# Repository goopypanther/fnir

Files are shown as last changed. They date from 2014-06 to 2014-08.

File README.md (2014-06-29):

fNIR: Functional Near-Infrared Brain Imaging
============================================

Similar to a pulse oximiter, an fNIR imager sends pulses of near infrared light into the body and records the intensity of the reflection to determine blood oxygen levels. At these frequencies bone is nearly transparent so sensors placed on the head can measure oxygen levels in the outer layers of the brain. These tend to correspond over time with the levels of activity of those regions.

This fNIR system has 8 groupings of transmitter LEDs and 10 receivers clustered around them which provides 16 measurement channels. Each LED cluster can illuminate the brain with either of two frequencies, one which reflects strongly off oxygenated hemoglobin and the other non-oxygenated. Calculating the ratio between the two yields the target's oxygen concentration.

The sensors are meant to be installed in a headband which can target the frontal lobe (short term memory, complex thought), primary motor cortex (voluntary movement), or even the broca's area or visual cortex.

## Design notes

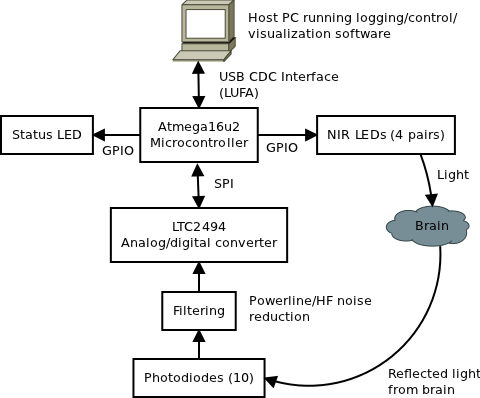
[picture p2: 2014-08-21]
system_design_document/system_design_document.png

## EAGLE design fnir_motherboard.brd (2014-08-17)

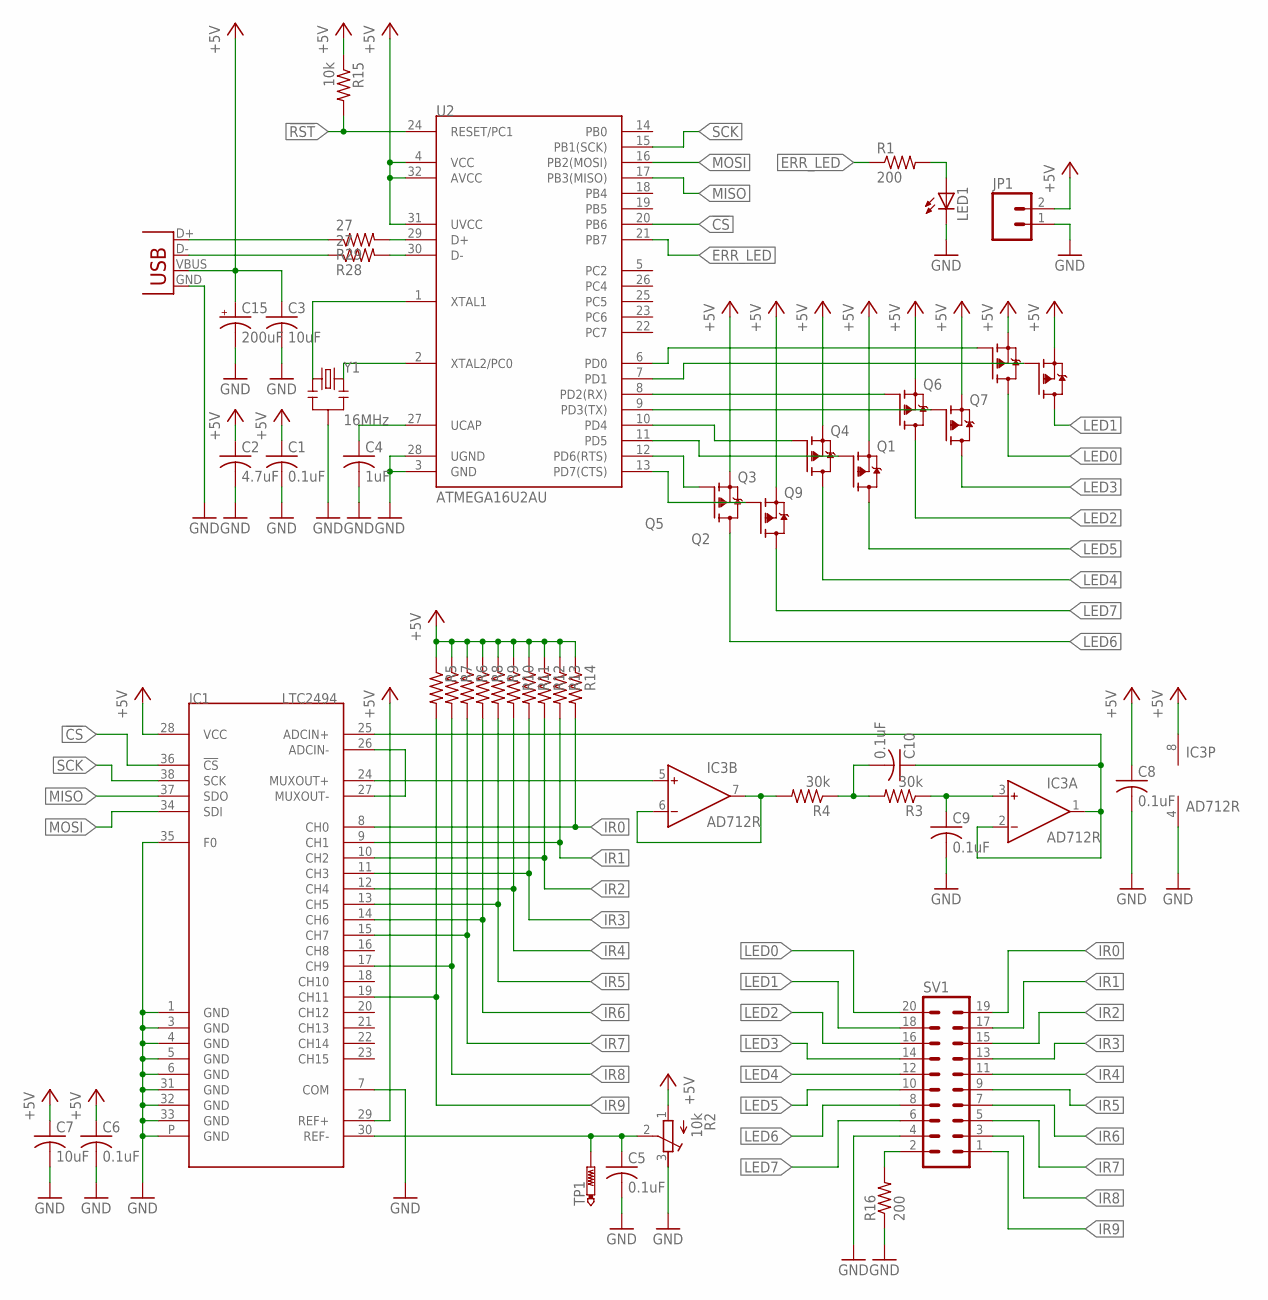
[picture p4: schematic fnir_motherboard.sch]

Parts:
C1, C5, C6, C8, C9, C10: 0.1uF; C1206
C2: 4.7uF; C1206
C3, C7: 10uF; C1206
C4: 1uF; C1206
C15: 200uF; PANASONIC_D
IC1: LTC2494; QFN38-7X12
IC3: AD712R; SO8
JP1: M02PTH; 1X02
LED1: LEDCHIPLED_1206; CHIPLED_1206
Q1, Q2, Q3, Q4, Q5, Q6, Q7, Q9: TRANSISTOR_FET_TSM2301CX; SOT-23
R1, R16: 200; R1206
R2: 10k; RTRIM3304W
R3, R4: 30k; R1206
R5, R6, R7, R8, R9, R10, R11, R12, R13, R14: R-US_R1206; R1206
R15: 10k; R1206
R28, R29: 27; R1206
SV1: MA10-2
TP1: PTR1B1,27; B1,27
U2: ATMEGA16U2AU; TQFP32-08
X2: USB-SMD-NS; USB-MINIB-NOSTOP
Y1: 16MHz; RESONATOR-SMD

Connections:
!CS: IC1.36 (!CS), U2.20 (PB6)
!RST: R15.2, U2.24 (RESET/PC1)
+5V: C1.1, C2.1, C3.1, C6.1, C7.1, C8.1, C15.+, IC1.28 (VCC), IC1.29 (REF+), IC3.8 (V+), JP1.2, Q1.2 (S), Q2.2 (S), Q3.2 (S), Q4.2 (S), Q5.2 (S), Q6.2 (S), Q7.2 (S), Q9.2 (S), R2.1 (A), R5.1, R6.1, R7.1, R8.1, R9.1, R10.1, R11.1, R12.1, R13.1, R14.1, R15.1, U2.4 (VCC), U2.31 (UVCC), U2.32 (AVCC), X2.VBUS
D+: R29.1, X2.D+
D-: R28.1, X2.D-
ERR_LED: R1.1, U2.21 (PB7)
GND: C1.2, C2.2, C3.2, C4.2, C5.2, C6.2, C7.2, C8.2, C9.2, C15.-, IC1.1 (GND), IC1.3 (GND), IC1.4 (GND), IC1.5 (GND), IC1.6 (GND), IC1.7 (COM), IC1.31 (GND), IC1.32 (GND), IC1.33 (GND), IC1.35 (F0), IC1.P (GND), IC3.4 (V-), JP1.1, LED1.C, R2.3 (E), R16.1, SV1.4, U2.3 (GND), U2.28 (UGND), X2.GND, Y1.2
IR0: IC1.8 (CH0), R14.2, SV1.19
IR1: IC1.9 (CH1), R13.2, SV1.17
IR2: IC1.10 (CH2), R12.2, SV1.15
IR3: IC1.11 (CH3), R11.2, SV1.13
IR4: IC1.12 (CH4), R10.2, SV1.11
IR5: IC1.13 (CH5), R9.2, SV1.9
IR6: IC1.14 (CH6), R8.2, SV1.7
IR7: IC1.15 (CH7), R6.2, SV1.5
IR8: IC1.17 (CH9), R7.2, SV1.3
IR9: IC1.19 (CH11), R5.2, SV1.1
LED0: Q6.3 (D), SV1.20
LED1: Q7.3 (D), SV1.18
LED2: Q4.3 (D), SV1.16
LED3: Q1.3 (D), SV1.14
LED4: Q3.3 (D), SV1.12
LED5: Q9.3 (D), SV1.10
LED6: Q5.3 (D), SV1.8
LED7: Q2.3 (D), SV1.6
MISO: IC1.37 (SDO), U2.17 (PB3(MISO))
MOSI: IC1.34 (SDI), U2.16 (PB2(MOSI))
unnamed: Q2.1 (G), U2.13 (PD7(CTS))
unnamed: Q1.1 (G), U2.9 (PD3(TX))
unnamed: Q9.1 (G), U2.11 (PD5)
unnamed: Q4.1 (G), U2.8 (PD2(RX))
unnamed: Q5.1 (G), U2.12 (PD6(RTS))
unnamed: Q7.1 (G), U2.7 (PD1)
unnamed: Q6.1 (G), U2.6 (PD0)
unnamed: Q3.1 (G), U2.10 (PD4)
unnamed: IC1.26 (ADCIN-), IC1.27 (MUXOUT-)
unnamed: IC1.24 (MUXOUT+), IC3.5 (IN+)
unnamed: C10.1, IC1.25 (ADCIN+), IC3.1 (OUT), IC3.2 (IN-)
unnamed: C5.1, IC1.30 (REF-), R2.2 (S), TP1.TP
unnamed: C9.1, IC3.3 (IN+), R3.1
unnamed: R28.2, U2.30 (D-)
unnamed: R29.2, U2.29 (D+)
unnamed: C10.2, R3.2, R4.1
unnamed: C4.1, U2.27 (UCAP)
unnamed: IC3.6 (IN-), IC3.7 (OUT), R4.2
unnamed: U2.2 (XTAL2/PC0), Y1.3
unnamed: U2.1 (XTAL1), Y1.1
unnamed: LED1.A, R1.2
unnamed: R16.2, SV1.2
SCK: IC1.38 (SCK), U2.15 (PB1(SCK))

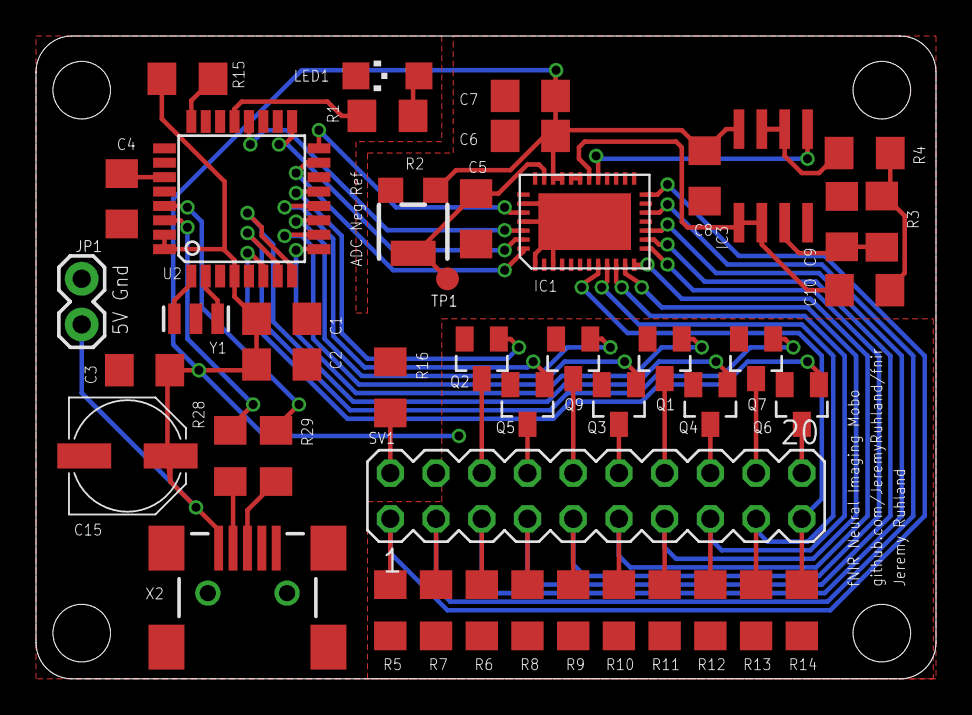
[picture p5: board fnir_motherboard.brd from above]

Board: 2 copper layers, 50.0 x 35.7 mm, 46 parts (0 on the bottom side), 50 nets.

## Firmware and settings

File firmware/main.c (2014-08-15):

/** @file main.c
* @brief fNIR Brain Imager
* @author Jeremy Ruhland
* @date 8/2014
*/

#include "includes.h"

// Private typedefs
/** USB system state enum */
typedef enum {USB_CONNECTED, /**< Usb system connected */
              USB_IDLE /**< Usb system disconnected */
} USB_sys_state_t;

/** fNIR scanning mode enum */
typedef enum {FNIR_NULL, /**< System is taking null offset measurement */
              FNIR_730NM, /**< System is taking 730nm measurement */
              FNIR_850NM, /**< System is taking 850nm measurement */
              FNIR_IDLE, /**< System is not currently taking any measurement */
              FNIR_STOP /**< System is paused and will not take measurements */
} fnir_mode_state_t;

// Private define macros
#define LED_ON() PORTB |= (1<<PB7)
#define LED_OFF() PORTB &= ~(1<<PB7)
#define LED_TOGGLE() PORTB ^= (1<<PB7)
#define CHIP_SELECT() PORTB |= (1<<PB6)
#define CHIP_DESELECT() PORTB &= ~(1<<PB6)

// Function prototypes
void mainIoInit(void);
void mainParseCommand(uint8_t receivedByte);
void mainFnirScan(void);
void mainNirLedControl(fnir_mode_state_t fnirMode, uint8_t channel);
adcReturn_t mainTakeMeasurement(uint8_t channel);
void mainReportResult(uint8_t channel, adcReturn_t *adcReturnValue);
void EVENT_USB_Device_Connect(void);
void EVENT_USB_Device_Disconnect(void);
void EVENT_USB_Device_ConfigurationChanged(void);
void EVENT_USB_Device_ControlRequest(void);

// Global variables
USB_sys_state_t USBSystemState;
fnir_mode_state_t fnirModeState;
static FILE USBSerialStream;

// Class define for USB CDC interface, taken from usb-serial example
USB_ClassInfo_CDC_Device_t VirtualSerial_CDC_Interface = {
    .Config = {
        .ControlInterfaceNumber = INTERFACE_ID_CDC_CCI,
        .DataINEndpoint = {
            .Address = CDC_TX_EPADDR,
            .Size = CDC_TXRX_EPSIZE,
            .Banks = 1,
        },
        .DataOUTEndpoint = {
            .Address = CDC_RX_EPADDR,
            .Size = CDC_TXRX_EPSIZE,
            .Banks = 1,
        },
        .NotificationEndpoint = {
            .Address = CDC_NOTIFICATION_EPADDR,
            .Size = CDC_NOTIFICATION_EPSIZE,
            .Banks = 1,
        },
    },
};

/** Main function
*
* Program begins here upon bootup
*
* @return This function should never exit.
*/
int main(void) {
    uint8_t receivedByte;

    USBSystemState = USB_IDLE;
    fnirModeState = FNIR_STOP;

    mainIoInit();
    spiInit();

    sei();

    for (;;) {
        switch (USBSystemState) {
        // When disconnected, attempt to reconnect
        case (USB_IDLE) :
            LED_TOGGLE();
            USB_Init();
            CDC_Device_CreateStream(&VirtualSerial_CDC_Interface, &USBSerialStream);
            break;

        // When connected, parse any received char and take measurements
        case (USB_CONNECTED) :
            LED_ON();
            receivedByte = fgetc(&USBSerialStream);
            mainParseCommand(receivedByte);
            mainFnirScan();

            // Calls to LUFA
            CDC_Device_USBTask(&VirtualSerial_CDC_Interface);
            USB_USBTask();
            break;

        default :
            break;
        }
    }
}

/** Initializes LED output for debug and NIR leds & SPI ports.
*
*/
void mainIoInit(void) {
    // Debug LED
    LED_OFF();
    DDRB |= (1<<PB7);

    // SPI
    DDRB |= ((1<<PB1)|(1<<PB2));

    // LED FETs
    mainNirLedControl(FNIR_NULL, 0);
    DDRD |= 0xFF; // Turn all port d IO to outputs
}

/** Parses commands received over usb-serial from host computer
*
* Checks the received byte from the usb serial stream device
* \ref USBSerialStream and passes it through a switch statement.
* Able to start and stop continuous measurements with chars \c s & \c p.
*
* @param receivedByte ASCII char received via usb-serial to be parsed
*/
void mainParseCommand(uint8_t receivedByte) {
    // Handle messages from host
    switch (receivedByte) {
    case (EOF) :
        break;

    case ('s') :
        fprintf(&USBSerialStream, "Starting\r\n");
        fnirModeState = FNIR_IDLE;
        break;

    case ('p') :
        fprintf(&USBSerialStream, "Stopping\r\n");
        fnirModeState = FNIR_STOP;

    default :
        break;
    }
}

/** Handles measurement of subject
*
* Cycles through all 16 channels, taking measurements with both types of LEDs
* as well as a non-LED measurement to calculate an offset value.
*
*/
void mainFnirScan(void) {
    static uint8_t measurementChannelSelected = 0;
    static adcReturn_t voltageLevel[3];

    switch (fnirModeState) {
    case (FNIR_NULL) :
        fnirModeState = FNIR_730NM;
        break;

    case (FNIR_730NM) :
        mainNirLedControl(fnirModeState, measurementChannelSelected);
        voltageLevel[0] = mainTakeMeasurement(measurementChannelSelected);
        fnirModeState = FNIR_850NM;
        break;

    case (FNIR_850NM) :
        mainNirLedControl(fnirModeState, measurementChannelSelected);
        voltageLevel[1] = mainTakeMeasurement(measurementChannelSelected);
        fnirModeState = FNIR_IDLE;
        break;

    case (FNIR_IDLE) :
        mainNirLedControl(fnirModeState, measurementChannelSelected);
        voltageLevel[2] = mainTakeMeasurement(measurementChannelSelected);
        fnirModeState = FNIR_NULL;

        // Send measurement via USB.
        mainReportResult(measurementChannelSelected, voltageLevel);

        // Move on to next measurement channel, or start back at 0
        if (measurementChannelSelected < 16) {
            measurementChannelSelected++;
        } else {
            measurementChannelSelected = 0;
        }
        break;

    case (FNIR_STOP) :
        break;

    default:
        break;
    }
}

/** Controls selection of near infrared leds.
*
* Channel may be 0-3, all leds will turn off when
* fnirMode == FNIR_IDLE | FNIR_NULL | FNIR_STOP.
*
* @param fnirMode LED type to activate
* @param channel led to activate
*/
void mainNirLedControl(fnir_mode_state_t fnirMode, uint8_t channel) {
    uint8_t ledChannel;

    ledChannel = channel/4; // Determine LED pair from desired channel

    // Activate proper led for desired mode and channel
    if (fnirMode == FNIR_730NM) {
        switch (ledChannel) {
        case 0 :
            PORTD = (1<<PD0);
            break;

        case 1 :
            PORTD = (1<<PD2);
            break;

        case 2 :
            PORTD = (1<<PD4);
            break;

        case 3 :
            PORTD = (1<<PD6);
            break;

        default :
            break;
        }
    } else if (fnirMode == FNIR_850NM) {
        switch (ledChannel) {
        case 0 :
            PORTD = (1<<PD1);
            break;

        case 1 :
            PORTD = (1<<PD3);
            break;

        case 2 :
            PORTD = (1<<PD5);
            break;

        case 3 :
            PORTD = (1<<PD7);
            break;

        default :
            break;
        }
    // If fnirMode was FNIR_IDLE|FNIR_NULL|FNIR_STOP
    } else {
        PORTD = 0x00; // Turn off all IO on port D
    }
}

/** Retrieves measurement from ADC
*
* Commands ADC to take measurement from selected channel with selected
* settings. Blocks until result is returned.
*
* @param channel channel of measurement to retrieve.
* @return measurement data
*/
adcReturn_t mainTakeMeasurement(uint8_t channel) {
    adcReturn_t adcReturnValue;
    adcChannelType_t adcChannel;

    // Determine multiplexer setup for desired channel
    switch (channel) {
    case 0 :
        adcChannel = UNIPOLAR_CH_0;
        break;

    case 1 :
        adcChannel = UNIPOLAR_CH_1;
        break;

    case 2 :
    case 4 :
        adcChannel = UNIPOLAR_CH_2;
        break;

    case 3 :
    case 5 :
        adcChannel = UNIPOLAR_CH_3;
        break;

    case 6 :
    case 8 :
        adcChannel = UNIPOLAR_CH_4;
        break;

    case 7 :
    case 9 :
        adcChannel = UNIPOLAR_CH_5;
        break;

    case 10 :
    case 12 :
        adcChannel = UNIPOLAR_CH_6;
        break;

    case 11 :
    case 13 :
        adcChannel = UNIPOLAR_CH_7;
        break;

    case 14 :
        adcChannel = UNIPOLAR_CH_9;
        break;

    case 15 :
        adcChannel = UNIPOLAR_CH_11;
        break;

    default :
        break;
    }

    CHIP_SELECT();

    // Command ADC to begin conversion
    (void) adcSelect(ENABLE,         // Enable adc
                     adcChannel,     // Select channel
                     REJECT_60HZ,    // Reject 60hz powerline noise
                     AUTO_CALIBRATE, // Slower but more accurate speed
                     GAIN_1X);       // Unity gain (no amplification)

    while (PORTB & (1<<PB3)) {} // Wait for conversion complete

    // Get return value while commanding ADC to shutdown
    adcReturnValue = adcSelect(DISABLE,        // Disable adc
                               NULL_CH,        // Null channel
                               NULL_REJECTION, // Null frequency rejection
                               NULL_SPEED,     // Null conversion speed
                               NULL_GAIN);     // Null signal gain

    CHIP_DESELECT();

    return (adcReturnValue);
}

/** Reports CVS dataset of measurements over USB
*
* TODO: calculate estimated oxy content from received values
*
* @param channel channel measured
* @param adcReturnValue array of measurements taken from specific channel
*/
void mainReportResult(uint8_t channel, adcReturn_t *adcReturnValue) {
    uint16_t estimatedOxyContent;

    fprintf(&USBSerialStream, "%d,%d,%d,%d,%d\r\n", // CSV string
            ((uint16_t) channel),                   // Reported channel
            adcReturnValue[0].returnValue,          // 730nm result
            adcReturnValue[1].returnValue,          // 850nm result
            adcReturnValue[2].returnValue,          // Dark result
            estimatedOxyContent);                   // Calculated oxy value
}

/** Event handler for the library USB Connection event. 
*
* Stops connection attempts from being made after the host device enumerates
* the system and prints "Device connected" onto the serial terminal.
* 
* @return This function does not return a value.
*/
void EVENT_USB_Device_Connect(void) {
    fprintf(&USBSerialStream, "Device Connected\r\n");
    USBSystemState = USB_CONNECTED;
}

/** Event handler for the library USB Disconnection event.
*
* Starts looping device connection attempts when if device becomes
* disconnected.
*
* @return This function does not return a value.
*/
void EVENT_USB_Device_Disconnect(void) {
    USBSystemState = USB_IDLE;
}

/** Event handler for the library USB Configuration Changed event.
*
*
* @return This function does not return a value.
*/
void EVENT_USB_Device_ConfigurationChanged(void) {
    CDC_Device_ConfigureEndpoints(&VirtualSerial_CDC_Interface);
}

/** Event handler for the library USB Control Request reception event.
*
* @return This function does not return a value.
*/
void EVENT_USB_Device_ControlRequest(void) {
    CDC_Device_ProcessControlRequest(&VirtualSerial_CDC_Interface);
}

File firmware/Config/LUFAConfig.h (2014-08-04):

/*
             LUFA Library
     Copyright (C) Dean Camera, 2014.

  dean [at] fourwalledcubicle [dot] com
           www.lufa-lib.org
*/

/*
  Copyright 2014  Dean Camera (dean [at] fourwalledcubicle [dot] com)

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
  The author disclaims all warranties with regard to this
  software, including all implied warranties of merchantability
  and fitness.  In no event shall the author be liable for any
  special, indirect or consequential damages or any damages
  whatsoever resulting from loss of use, data or profits, whether
  in an action of contract, negligence or other tortious action,
  arising out of or in connection with the use or performance of
  this software.
*/

/** \file
 *  \brief LUFA Library Configuration Header File
 *
 *  This header file is used to configure LUFA's compile time options,
 *  as an alternative to the compile time constants supplied through
 *  a makefile.
 *
 *  For information on what each token does, refer to the LUFA
 *  manual section "Summary of Compile Tokens".
 */

#ifndef _LUFA_CONFIG_H_
#define _LUFA_CONFIG_H_

	#if (ARCH == ARCH_AVR8)
		/* Non-USB Related Configuration Tokens: */
//		#define DISABLE_TERMINAL_CODES

		/* USB Class Driver Related Tokens: */
//		#define HID_HOST_BOOT_PROTOCOL_ONLY
//		#define HID_STATETABLE_STACK_DEPTH       {Insert Value Here}
//		#define HID_USAGE_STACK_DEPTH            {Insert Value Here}
//		#define HID_MAX_COLLECTIONS              {Insert Value Here}
//		#define HID_MAX_REPORTITEMS              {Insert Value Here}
//		#define HID_MAX_REPORT_IDS               {Insert Value Here}
//		#define NO_CLASS_DRIVER_AUTOFLUSH

		/* General USB Driver Related Tokens: */
//		#define ORDERED_EP_CONFIG
		#define USE_STATIC_OPTIONS               (USB_DEVICE_OPT_FULLSPEED | USB_OPT_REG_ENABLED | USB_OPT_AUTO_PLL)
		#define USB_DEVICE_ONLY
//		#define USB_HOST_ONLY
//		#define USB_STREAM_TIMEOUT_MS            {Insert Value Here}
//		#define NO_LIMITED_CONTROLLER_CONNECT
//		#define NO_SOF_EVENTS

		/* USB Device Mode Driver Related Tokens: */
//		#define USE_RAM_DESCRIPTORS
		#define USE_FLASH_DESCRIPTORS
//		#define USE_EEPROM_DESCRIPTORS
//		#define NO_INTERNAL_SERIAL
		#define FIXED_CONTROL_ENDPOINT_SIZE      8
//		#define DEVICE_STATE_AS_GPIOR            {Insert Value Here}
		#define FIXED_NUM_CONFIGURATIONS         1
//		#define CONTROL_ONLY_DEVICE
		#define INTERRUPT_CONTROL_ENDPOINT
//		#define NO_DEVICE_REMOTE_WAKEUP
//		#define NO_DEVICE_SELF_POWER

		/* USB Host Mode Driver Related Tokens: */
//		#define HOST_STATE_AS_GPIOR              {Insert Value Here}
//		#define USB_HOST_TIMEOUT_MS              {Insert Value Here}
//		#define HOST_DEVICE_SETTLE_DELAY_MS	     {Insert Value Here}
//		#define NO_AUTO_VBUS_MANAGEMENT
//		#define INVERTED_VBUS_ENABLE_LINE

	#elif (ARCH == ARCH_XMEGA)

		/* Non-USB Related Configuration Tokens: */
//		#define DISABLE_TERMINAL_CODES

		/* USB Class Driver Related Tokens: */
//		#define HID_HOST_BOOT_PROTOCOL_ONLY
//		#define HID_STATETABLE_STACK_DEPTH       {Insert Value Here}
//		#define HID_USAGE_STACK_DEPTH            {Insert Value Here}
//		#define HID_MAX_COLLECTIONS              {Insert Value Here}
//		#define HID_MAX_REPORTITEMS              {Insert Value Here}
//		#define HID_MAX_REPORT_IDS               {Insert Value Here}
//		#define NO_CLASS_DRIVER_AUTOFLUSH

		/* General USB Driver Related Tokens: */
		#define USE_STATIC_OPTIONS               (USB_DEVICE_OPT_FULLSPEED | USB_OPT_RC32MCLKSRC | USB_OPT_BUSEVENT_PRIHIGH)
//		#define USB_STREAM_TIMEOUT_MS            {Insert Value Here}
//		#define NO_LIMITED_CONTROLLER_CONNECT
//		#define NO_SOF_EVENTS

		/* USB Device Mode Driver Related Tokens: */
//		#define USE_RAM_DESCRIPTORS
		#define USE_FLASH_DESCRIPTORS
//		#define USE_EEPROM_DESCRIPTORS
//		#define NO_INTERNAL_SERIAL
		#define FIXED_CONTROL_ENDPOINT_SIZE      8
//		#define DEVICE_STATE_AS_GPIOR            {Insert Value Here}
		#define FIXED_NUM_CONFIGURATIONS         1
//		#define CONTROL_ONLY_DEVICE
		#define MAX_ENDPOINT_INDEX               4
//		#define NO_DEVICE_REMOTE_WAKEUP
//		#define NO_DEVICE_SELF_POWER

	#else

		#error Unsupported architecture for this LUFA configuration file.

	#endif
#endif

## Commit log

2014-06-27 designed qfn version
    [fnir_motherboard.brd, fnir_motherboard.sch]
2014-06-28 new version desinged
    [fnir_motherboard.brd, fnir_motherboard.sch]
2014-07-21 slight changes to pour layouts for ground and agnd (merged)
    [fnir_motherboard.brd, fnir_motherboard.sch]
2014-07-21 starting adc c library
2014-08-04 fixed slight error in adc module, some semis missing
    [2494_adc.c]
2014-08-04 copied over spi module from old project, may need to change settings
2014-08-13 Added docs for spi system
2014-08-13 added doxygen for adc
2014-08-17 updated sch and makefile for 16u2, more space to fit firmware with dfu usb bootloader
    [fnir_motherboard.brd, fnir_motherboard.sch]

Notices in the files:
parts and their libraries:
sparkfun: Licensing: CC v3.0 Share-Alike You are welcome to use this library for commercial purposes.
